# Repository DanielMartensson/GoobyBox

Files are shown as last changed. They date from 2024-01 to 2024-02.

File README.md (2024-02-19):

# GoobyBox

This project is `GoobyBox`. It's an IO-shield for Arduino UNO. 
The purpose with this project is to provide a simple solution for controlling:

 * 4 x Analog 0-10V inputs
 * 3 x PWM current 0-2A
 * 3 x Digital output current 0-2A
 * 6 x Digital input 24V protection
 * 12/24 voltage supply
 * I2C connection for LCD

This project contains two projects - Surface Mounted Technology(SMT) and Through Hole Technology Mounting (THT).

Software being used: KiCAD 6

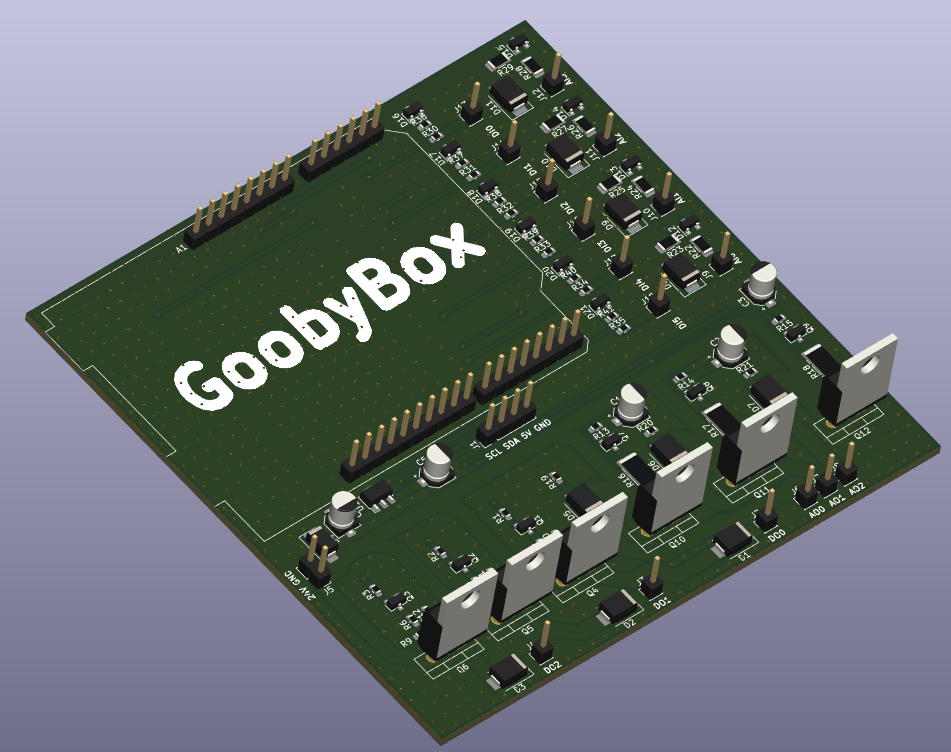
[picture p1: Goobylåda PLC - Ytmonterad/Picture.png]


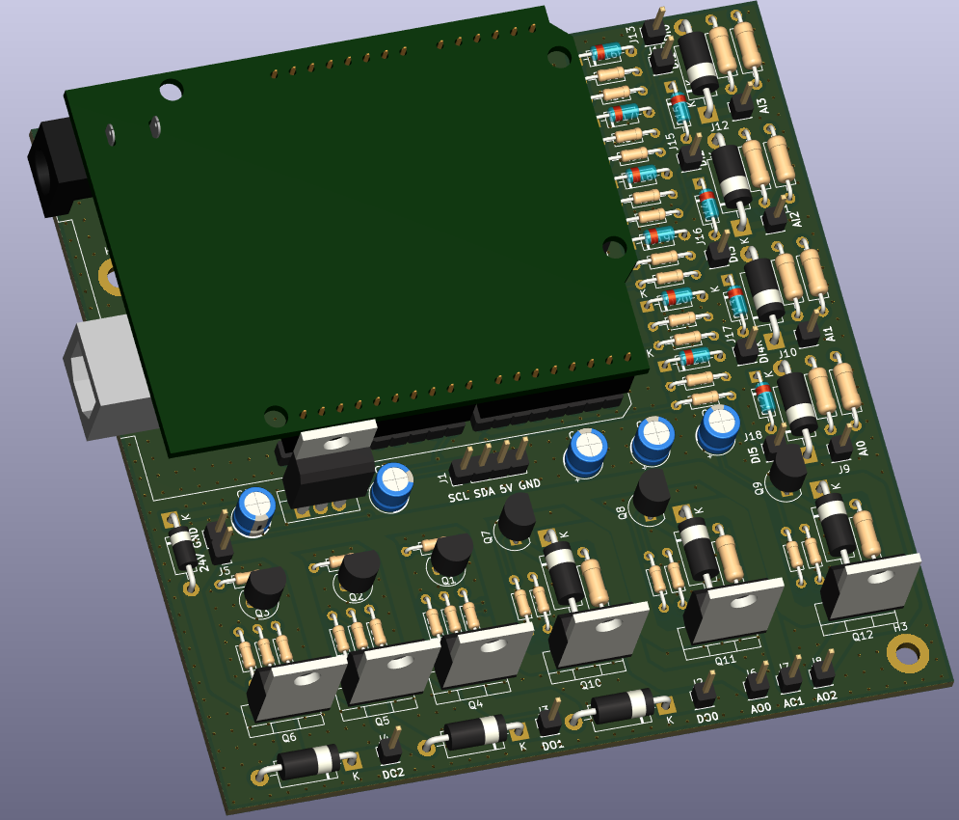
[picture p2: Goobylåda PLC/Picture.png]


This is soldered according to class 3 in the soldering and assembly standard IPC J-STD-001.

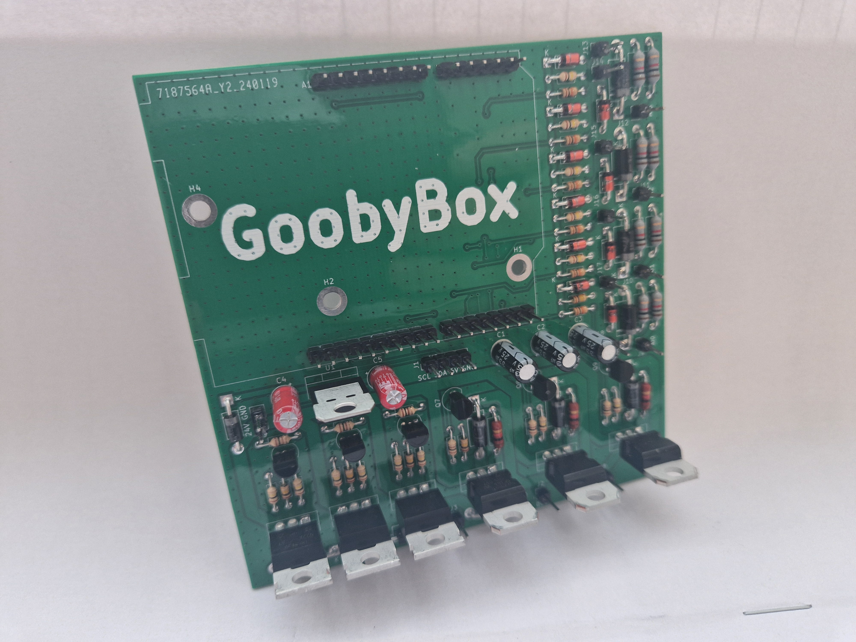
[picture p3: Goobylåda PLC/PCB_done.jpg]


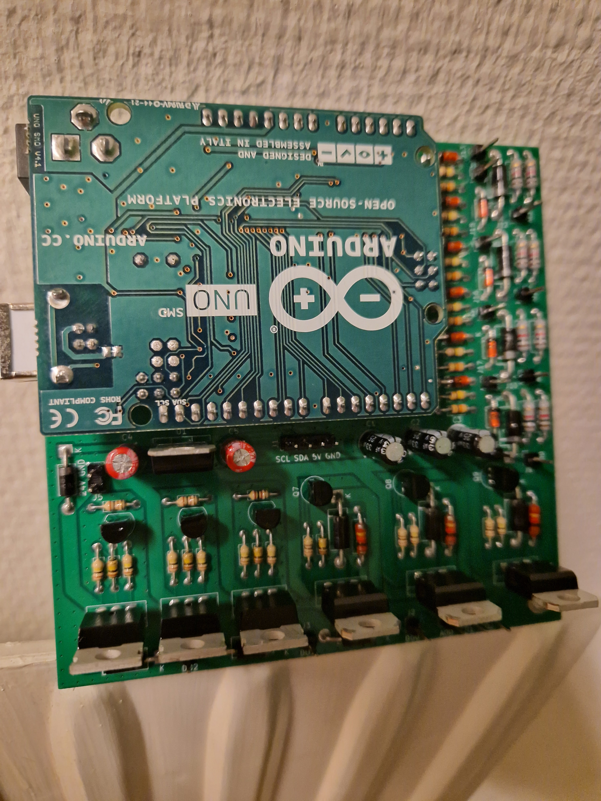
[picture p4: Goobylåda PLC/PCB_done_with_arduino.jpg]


a

Notice that I'm using a `EBC`-transistor here instead of `CBE`-transistor for the analog output.

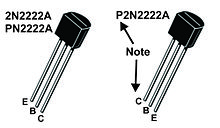
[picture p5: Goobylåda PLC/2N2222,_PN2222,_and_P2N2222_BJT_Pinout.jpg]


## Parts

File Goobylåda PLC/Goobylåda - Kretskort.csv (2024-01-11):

Source: | G:\Utbildning\Kurskatalog\4.04. Styr och Reglerteknik\7 Övningar\Laborationer\Goobylåda\Goobylåda PLC\Goobylåda - Kretskort.kicad_sch
Date: | 2022-08-26 13:30:34
Tool: | Eeschema (6.0.7)
Generator: | C:\Program Files\KiCad\6.0\bin\scripting\plugins/bom_csv_grouped_by_value.py
Component Count: | 99
Individual Components:
Item | Qty | Reference(s) | Value | LibPart | Footprint | Datasheet
 |  | A1 | Arduino_UNO_R3 | MCU_Module:Arduino_UNO_R3 | Module:Arduino_UNO_R3 | https://www.arduino.cc/en/Main/arduinoBoardUno
 |  | C1 | 33uF | Goobylåda---Kretskort-rescue:CP-Device | Capacitor_THT:CP_Radial_D5.0mm_P2.00mm
 |  | C2 | 33uF | Goobylåda---Kretskort-rescue:CP-Device | Capacitor_THT:CP_Radial_D5.0mm_P2.00mm
 |  | C3 | 33uF | Goobylåda---Kretskort-rescue:CP-Device | Capacitor_THT:CP_Radial_D5.0mm_P2.00mm
 |  | C4 | 0.33uF | Goobylåda---Kretskort-rescue:CP-Device | Capacitor_THT:CP_Radial_D5.0mm_P2.00mm
 |  | C5 | 0.1uF | Goobylåda---Kretskort-rescue:CP-Device | Capacitor_THT:CP_Radial_D5.0mm_P2.00mm
 |  | D1 | 1N5400K | Device:D | Diode_THT:D_DO-15_P10.16mm_Horizontal | ~
 |  | D2 | 1N5400K | Device:D | Diode_THT:D_DO-15_P10.16mm_Horizontal | ~
 |  | D3 | 1N5400K | Device:D | Diode_THT:D_DO-15_P10.16mm_Horizontal | ~
 |  | D4 | 600V 1A | Device:D | Diode_THT:D_DO-41_SOD81_P7.62mm_Horizontal | ~
 |  | D5 | 1N5400K | Device:D | Diode_THT:D_DO-15_P10.16mm_Horizontal | ~
 |  | D6 | 1N5400K | Device:D | Diode_THT:D_DO-15_P10.16mm_Horizontal | ~
 |  | D7 | 1N5400K | Device:D | Diode_THT:D_DO-15_P10.16mm_Horizontal | ~
 |  | D8 | 1N5400K | Device:D | Diode_THT:D_DO-15_P10.16mm_Horizontal | ~
 |  | D9 | 1N5400K | Device:D | Diode_THT:D_DO-15_P10.16mm_Horizontal | ~
 |  | D10 | 1N5400K | Device:D | Diode_THT:D_DO-15_P10.16mm_Horizontal | ~
 |  | D11 | 1N5400K | Device:D | Diode_THT:D_DO-15_P10.16mm_Horizontal | ~
 |  | D12 | 5.2V | Device:D_Zener | Diode_THT:D_DO-35_SOD27_P7.62mm_Horizontal | ~
 |  | D13 | 5.2V | Device:D_Zener | Diode_THT:D_DO-35_SOD27_P7.62mm_Horizontal | ~
 |  | D14 | 5.2V | Device:D_Zener | Diode_THT:D_DO-35_SOD27_P7.62mm_Horizontal | ~
 |  | D15 | 5.2V | Device:D_Zener | Diode_THT:D_DO-35_SOD27_P7.62mm_Horizontal | ~
 |  | D16 | 5.2V | Device:D_Zener | Diode_THT:D_DO-35_SOD27_P7.62mm_Horizontal | ~
 |  | D17 | 5.2V | Device:D_Zener | Diode_THT:D_DO-35_SOD27_P7.62mm_Horizontal | ~
 |  | D18 | 5.2V | Device:D_Zener | Diode_THT:D_DO-35_SOD27_P7.62mm_Horizontal | ~
 |  | D19 | 5.2V | Device:D_Zener | Diode_THT:D_DO-35_SOD27_P7.62mm_Horizontal | ~
 |  | D20 | 5.2V | Device:D_Zener | Diode_THT:D_DO-35_SOD27_P7.62mm_Horizontal | ~
 |  | D21 | 5.2V | Device:D_Zener | Diode_THT:D_DO-35_SOD27_P7.62mm_Horizontal | ~
 |  | J1 | LCD 1602 kontakt | Connector_Generic:Conn_01x04 | Connector_PinHeader_2.54mm:PinHeader_1x04_P2.54mm_Vertical | ~
 |  | J2 | Anslutning | Connector_Generic:Conn_01x01 | Connector_PinHeader_2.54mm:PinHeader_1x01_P2.54mm_Vertical | ~
 |  | J3 | Anslutning | Connector_Generic:Conn_01x01 | Connector_PinHeader_2.54mm:PinHeader_1x01_P2.54mm_Vertical | ~
 |  | J4 | Anslutning | Connector_Generic:Conn_01x01 | Connector_PinHeader_2.54mm:PinHeader_1x01_P2.54mm_Vertical | ~
 |  | J5 | Anslutning | Connector_Generic:Conn_01x02 | Connector_PinHeader_2.54mm:PinHeader_1x02_P2.54mm_Vertical | ~
 |  | J6 | Anslutning | Connector_Generic:Conn_01x01 | Connector_PinHeader_2.54mm:PinHeader_1x01_P2.54mm_Vertical | ~
 |  | J7 | Anslutning | Connector_Generic:Conn_01x01 | Connector_PinHeader_2.54mm:PinHeader_1x01_P2.54mm_Vertical | ~
 |  | J8 | Anslutning | Connector_Generic:Conn_01x01 | Connector_PinHeader_2.54mm:PinHeader_1x01_P2.54mm_Vertical | ~
 |  | J9 | Anslutning | Connector_Generic:Conn_01x01 | Connector_PinHeader_2.54mm:PinHeader_1x01_P2.54mm_Vertical | ~
 |  | J10 | Anslutning | Connector_Generic:Conn_01x01 | Connector_PinHeader_2.54mm:PinHeader_1x01_P2.54mm_Vertical | ~
 |  | J11 | Anslutning | Connector_Generic:Conn_01x01 | Connector_PinHeader_2.54mm:PinHeader_1x01_P2.54mm_Vertical | ~
 |  | J12 | Anslutning | Connector_Generic:Conn_01x01 | Connector_PinHeader_2.54mm:PinHeader_1x01_P2.54mm_Vertical | ~
 |  | J13 | Anslutning | Connector_Generic:Conn_01x01 | Connector_PinHeader_2.54mm:PinHeader_1x01_P2.54mm_Vertical | ~
 |  | J14 | Anslutning | Connector_Generic:Conn_01x01 | Connector_PinHeader_2.54mm:PinHeader_1x01_P2.54mm_Vertical | ~
 |  | J15 | Anslutning | Connector_Generic:Conn_01x01 | Connector_PinHeader_2.54mm:PinHeader_1x01_P2.54mm_Vertical | ~
 |  | J16 | Anslutning | Connector_Generic:Conn_01x01 | Connector_PinHeader_2.54mm:PinHeader_1x01_P2.54mm_Vertical | ~
 |  | J17 | Anslutning | Connector_Generic:Conn_01x01 | Connector_PinHeader_2.54mm:PinHeader_1x01_P2.54mm_Vertical | ~
 |  | J18 | Anslutning | Connector_Generic:Conn_01x01 | Connector_PinHeader_2.54mm:PinHeader_1x01_P2.54mm_Vertical | ~
 |  | Q1 | 2N2222 | Transistor_BJT:2N2219 | Package_TO_SOT_THT:TO-92 | http://www.onsemi.com/pub_link/Collateral/2N2219-D.PDF
 |  | Q2 | 2N2222 | Transistor_BJT:2N2219 | Package_TO_SOT_THT:TO-92 | http://www.onsemi.com/pub_link/Collateral/2N2219-D.PDF
 |  | Q3 | 2N2222 | Transistor_BJT:2N2219 | Package_TO_SOT_THT:TO-92 | http://www.onsemi.com/pub_link/Collateral/2N2219-D.PDF
 |  | Q4 | IRF9630 | Transistor_FET:IRF9383M | Package_TO_SOT_THT:TO-220-3_Vertical | https://www.infineon.com/dgdl/irf9383mpbf.pdf?fileId=5546d462533600a40153561169a11dab
 |  | Q5 | IRF9630 | Transistor_FET:IRF9383M | Package_TO_SOT_THT:TO-220-3_Vertical | https://www.infineon.com/dgdl/irf9383mpbf.pdf?fileId=5546d462533600a40153561169a11dab
 |  | Q6 | IRF9630 | Transistor_FET:IRF9383M | Package_TO_SOT_THT:TO-220-3_Vertical | https://www.infineon.com/dgdl/irf9383mpbf.pdf?fileId=5546d462533600a40153561169a11dab
 |  | Q7 | 2N2222 | Transistor_BJT:2N2219 | Package_TO_SOT_THT:TO-92 | http://www.onsemi.com/pub_link/Collateral/2N2219-D.PDF
 |  | Q8 | 2N2222 | Transistor_BJT:2N2219 | Package_TO_SOT_THT:TO-92 | http://www.onsemi.com/pub_link/Collateral/2N2219-D.PDF
 |  | Q9 | 2N2222 | Transistor_BJT:2N2219 | Package_TO_SOT_THT:TO-92 | http://www.onsemi.com/pub_link/Collateral/2N2219-D.PDF
 |  | Q10 | MJE2955T | Transistor_BJT:MJ2955 | Package_TO_SOT_THT:TO-220-3_Vertical | http://www.onsemi.com/pub_link/Collateral/2N3055-D.PDF
 |  | Q11 | MJE2955T | Transistor_BJT:MJ2955 | Package_TO_SOT_THT:TO-220-3_Vertical | http://www.onsemi.com/pub_link/Collateral/2N3055-D.PDF
 |  | Q12 | MJE2955T | Transistor_BJT:MJ2955 | Package_TO_SOT_THT:TO-220-3_Vertical | http://www.onsemi.com/pub_link/Collateral/2N3055-D.PDF
 |  | R1 | 100 | Device:R | Resistor_THT:R_Axial_DIN0204_L3.6mm_D1.6mm_P5.08mm_Horizontal | ~
 |  | R2 | 100 | Device:R | Resistor_THT:R_Axial_DIN0204_L3.6mm_D1.6mm_P5.08mm_Horizontal | ~
 |  | R3 | 100 | Device:R | Resistor_THT:R_Axial_DIN0204_L3.6mm_D1.6mm_P5.08mm_Horizontal | ~
 |  | R4 | 100k | Device:R | Resistor_THT:R_Axial_DIN0204_L3.6mm_D1.6mm_P5.08mm_Horizontal | ~
 |  | R5 | 100k | Device:R | Resistor_THT:R_Axial_DIN0204_L3.6mm_D1.6mm_P5.08mm_Horizontal | ~
 |  | R6 | 100k | Device:R | Resistor_THT:R_Axial_DIN0204_L3.6mm_D1.6mm_P5.08mm_Horizontal | ~
 |  | R7 | 100k | Device:R | Resistor_THT:R_Axial_DIN0204_L3.6mm_D1.6mm_P5.08mm_Horizontal | ~
 |  | R8 | 100k | Device:R | Resistor_THT:R_Axial_DIN0204_L3.6mm_D1.6mm_P5.08mm_Horizontal | ~
 |  | R9 | 100k | Device:R | Resistor_THT:R_Axial_DIN0204_L3.6mm_D1.6mm_P5.08mm_Horizontal | ~
 |  | R10 | 100k | Device:R | Resistor_THT:R_Axial_DIN0204_L3.6mm_D1.6mm_P5.08mm_Horizontal | ~
 |  | R11 | 100k | Device:R | Resistor_THT:R_Axial_DIN0204_L3.6mm_D1.6mm_P5.08mm_Horizontal | ~
 |  | R12 | 100k | Device:R | Resistor_THT:R_Axial_DIN0204_L3.6mm_D1.6mm_P5.08mm_Horizontal | ~
 |  | R13 | 100 | Device:R | Resistor_THT:R_Axial_DIN0204_L3.6mm_D1.6mm_P5.08mm_Horizontal | ~
 |  | R14 | 100 | Device:R | Resistor_THT:R_Axial_DIN0204_L3.6mm_D1.6mm_P5.08mm_Horizontal | ~
 |  | R15 | 100 | Device:R | Resistor_THT:R_Axial_DIN0204_L3.6mm_D1.6mm_P5.08mm_Horizontal | ~
 |  | R16 | 1k, 1W | Device:R | Resistor_THT:R_Axial_DIN0207_L6.3mm_D2.5mm_P10.16mm_Horizontal | ~
 |  | R17 | 1k, 1W | Device:R | Resistor_THT:R_Axial_DIN0207_L6.3mm_D2.5mm_P10.16mm_Horizontal | ~
 |  | R18 | 1k, 1W | Device:R | Resistor_THT:R_Axial_DIN0207_L6.3mm_D2.5mm_P10.16mm_Horizontal | ~
 |  | R19 | 100k | Device:R | Resistor_THT:R_Axial_DIN0204_L3.6mm_D1.6mm_P5.08mm_Horizontal | ~
 |  | R20 | 100k | Device:R | Resistor_THT:R_Axial_DIN0204_L3.6mm_D1.6mm_P5.08mm_Horizontal | ~
 |  | R21 | 100k | Device:R | Resistor_THT:R_Axial_DIN0204_L3.6mm_D1.6mm_P5.08mm_Horizontal | ~
 |  | R22 | 1k, 250 mW | Device:R | Resistor_THT:R_Axial_DIN0204_L3.6mm_D1.6mm_P5.08mm_Horizontal | ~
 |  | R23 | 1k, 250 mW | Device:R | Resistor_THT:R_Axial_DIN0204_L3.6mm_D1.6mm_P5.08mm_Horizontal | ~
 |  | R24 | 1k, 250 mW | Device:R | Resistor_THT:R_Axial_DIN0204_L3.6mm_D1.6mm_P5.08mm_Horizontal | ~
 |  | R25 | 1k, 250 mW | Device:R | Resistor_THT:R_Axial_DIN0204_L3.6mm_D1.6mm_P5.08mm_Horizontal | ~
 |  | R26 | 1k, 250 mW | Device:R | Resistor_THT:R_Axial_DIN0204_L3.6mm_D1.6mm_P5.08mm_Horizontal | ~
 |  | R27 | 1k, 250 mW | Device:R | Resistor_THT:R_Axial_DIN0204_L3.6mm_D1.6mm_P5.08mm_Horizontal | ~
 |  | R28 | 1k, 250 mW | Device:R | Resistor_THT:R_Axial_DIN0204_L3.6mm_D1.6mm_P5.08mm_Horizontal | ~
 |  | R29 | 1k, 250 mW | Device:R | Resistor_THT:R_Axial_DIN0204_L3.6mm_D1.6mm_P5.08mm_Horizontal | ~
 |  | R30 | 10k | Device:R | Resistor_THT:R_Axial_DIN0204_L3.6mm_D1.6mm_P5.08mm_Horizontal | ~
 |  | R31 | 10k | Device:R | Resistor_THT:R_Axial_DIN0204_L3.6mm_D1.6mm_P5.08mm_Horizontal | ~
 |  | R32 | 10k | Device:R | Resistor_THT:R_Axial_DIN0204_L3.6mm_D1.6mm_P5.08mm_Horizontal | ~
 |  | R33 | 10k | Device:R | Resistor_THT:R_Axial_DIN0204_L3.6mm_D1.6mm_P5.08mm_Horizontal | ~
 |  | R34 | 10k | Device:R | Resistor_THT:R_Axial_DIN0204_L3.6mm_D1.6mm_P5.08mm_Horizontal | ~
 |  | R35 | 10k | Device:R | Resistor_THT:R_Axial_DIN0204_L3.6mm_D1.6mm_P5.08mm_Horizontal | ~
 |  | R36 | 100k | Device:R | Resistor_THT:R_Axial_DIN0204_L3.6mm_D1.6mm_P5.08mm_Horizontal | ~
 |  | R37 | 100k | Device:R | Resistor_THT:R_Axial_DIN0204_L3.6mm_D1.6mm_P5.08mm_Horizontal | ~
 |  | R38 | 100k | Device:R | Resistor_THT:R_Axial_DIN0204_L3.6mm_D1.6mm_P5.08mm_Horizontal | ~
 |  | R39 | 100k | Device:R | Resistor_THT:R_Axial_DIN0204_L3.6mm_D1.6mm_P5.08mm_Horizontal | ~
 |  | R40 | 100k | Device:R | Resistor_THT:R_Axial_DIN0204_L3.6mm_D1.6mm_P5.08mm_Horizontal | ~
 |  | R41 | 100k | Device:R | Resistor_THT:R_Axial_DIN0204_L3.6mm_D1.6mm_P5.08mm_Horizontal | ~
 |  | U1 | LM7812_TO220 | Regulator_Linear:LM7812_TO220 | Package_TO_SOT_THT:TO-220-3_Vertical | https://www.onsemi.cn/PowerSolutions/document/MC7800-D.PDF
Collated Components:
Item | Qty | Reference(s) | Value | LibPart | Footprint | Datasheet
1 | 1 | A1 | Arduino_UNO_R3 | MCU_Module:Arduino_UNO_R3 | Module:Arduino_UNO_R3 | https://www.arduino.cc/en/Main/arduinoBoardUno
2 | 3 | C1, C2, C3 | 33uF | Goobylåda---Kretskort-rescue:CP-Device | Capacitor_THT:CP_Radial_D5.0mm_P2.00mm
3 | 1 | C4 | 0.33uF | Goobylåda---Kretskort-rescue:CP-Device | Capacitor_THT:CP_Radial_D5.0mm_P2.00mm
4 | 1 | C5 | 0.1uF | Goobylåda---Kretskort-rescue:CP-Device | Capacitor_THT:CP_Radial_D5.0mm_P2.00mm
5 | 10 | D1, D2, D3, D5, D6, D7, D8, D9, D10, D11 | 1N5400K | Device:D | Diode_THT:D_DO-15_P10.16mm_Horizontal | ~
6 | 1 | D4 | 600V 1A | Device:D | Diode_THT:D_DO-41_SOD81_P7.62mm_Horizontal | ~
7 | 10 | D12, D13, D14, D15, D16, D17, D18, D19, D20, D21 | 5.2V | Device:D_Zener | Diode_THT:D_DO-35_SOD27_P7.62mm_Horizontal | ~
8 | 1 | J1 | LCD 1602 kontakt | Connector_Generic:Conn_01x04 | Connector_PinHeader_2.54mm:PinHeader_1x04_P2.54mm_Vertical | ~
9 | 16 | J2, J3, J4, J6, J7, J8, J9, J10, J11, J12, J13, J14, J15, J16, J17, J18 | Anslutning | Connector_Generic:Conn_01x01 | Connector_PinHeader_2.54mm:PinHeader_1x01_P2.54mm_Vertical | ~
10 | 1 | J5 | Anslutning | Connector_Generic:Conn_01x02 | Connector_PinHeader_2.54mm:PinHeader_1x02_P2.54mm_Vertical | ~
11 | 6 | Q1, Q2, Q3, Q7, Q8, Q9 | 2N2222 | Transistor_BJT:2N2219 | Package_TO_SOT_THT:TO-92 | http://www.onsemi.com/pub_link/Collateral/2N2219-D.PDF
12 | 3 | Q4, Q5, Q6 | IRF9630 | Transistor_FET:IRF9383M | Package_TO_SOT_THT:TO-220-3_Vertical | https://www.infineon.com/dgdl/irf9383mpbf.pdf?fileId=5546d462533600a40153561169a11dab
13 | 3 | Q10, Q11, Q12 | MJE2955T | Transistor_BJT:MJ2955 | Package_TO_SOT_THT:TO-220-3_Vertical | http://www.onsemi.com/pub_link/Collateral/2N3055-D.PDF
14 | 6 | R1, R2, R3, R13, R14, R15 | 100 | Device:R | Resistor_THT:R_Axial_DIN0204_L3.6mm_D1.6mm_P5.08mm_Horizontal | ~
15 | 18 | R4, R5, R6, R7, R8, R9, R10, R11, R12, R19, R20, R21, R36, R37, R38, R39, R40, R41 | 100k | Device:R | Resistor_THT:R_Axial_DIN0204_L3.6mm_D1.6mm_P5.08mm_Horizontal | ~
16 | 3 | R16, R17, R18 | 1k, 1W | Device:R | Resistor_THT:R_Axial_DIN0207_L6.3mm_D2.5mm_P10.16mm_Horizontal | ~
17 | 8 | R22, R23, R24, R25, R26, R27, R28, R29 | 1k, 250 mW | Device:R | Resistor_THT:R_Axial_DIN0204_L3.6mm_D1.6mm_P5.08mm_Horizontal | ~
18 | 6 | R30, R31, R32, R33, R34, R35 | 10k | Device:R | Resistor_THT:R_Axial_DIN0204_L3.6mm_D1.6mm_P5.08mm_Horizontal | ~
19 | 1 | U1 | LM7812_TO220 | Regulator_Linear:LM7812_TO220 | Package_TO_SOT_THT:TO-220-3_Vertical | https://www.onsemi.cn/PowerSolutions/document/MC7800-D.PDF

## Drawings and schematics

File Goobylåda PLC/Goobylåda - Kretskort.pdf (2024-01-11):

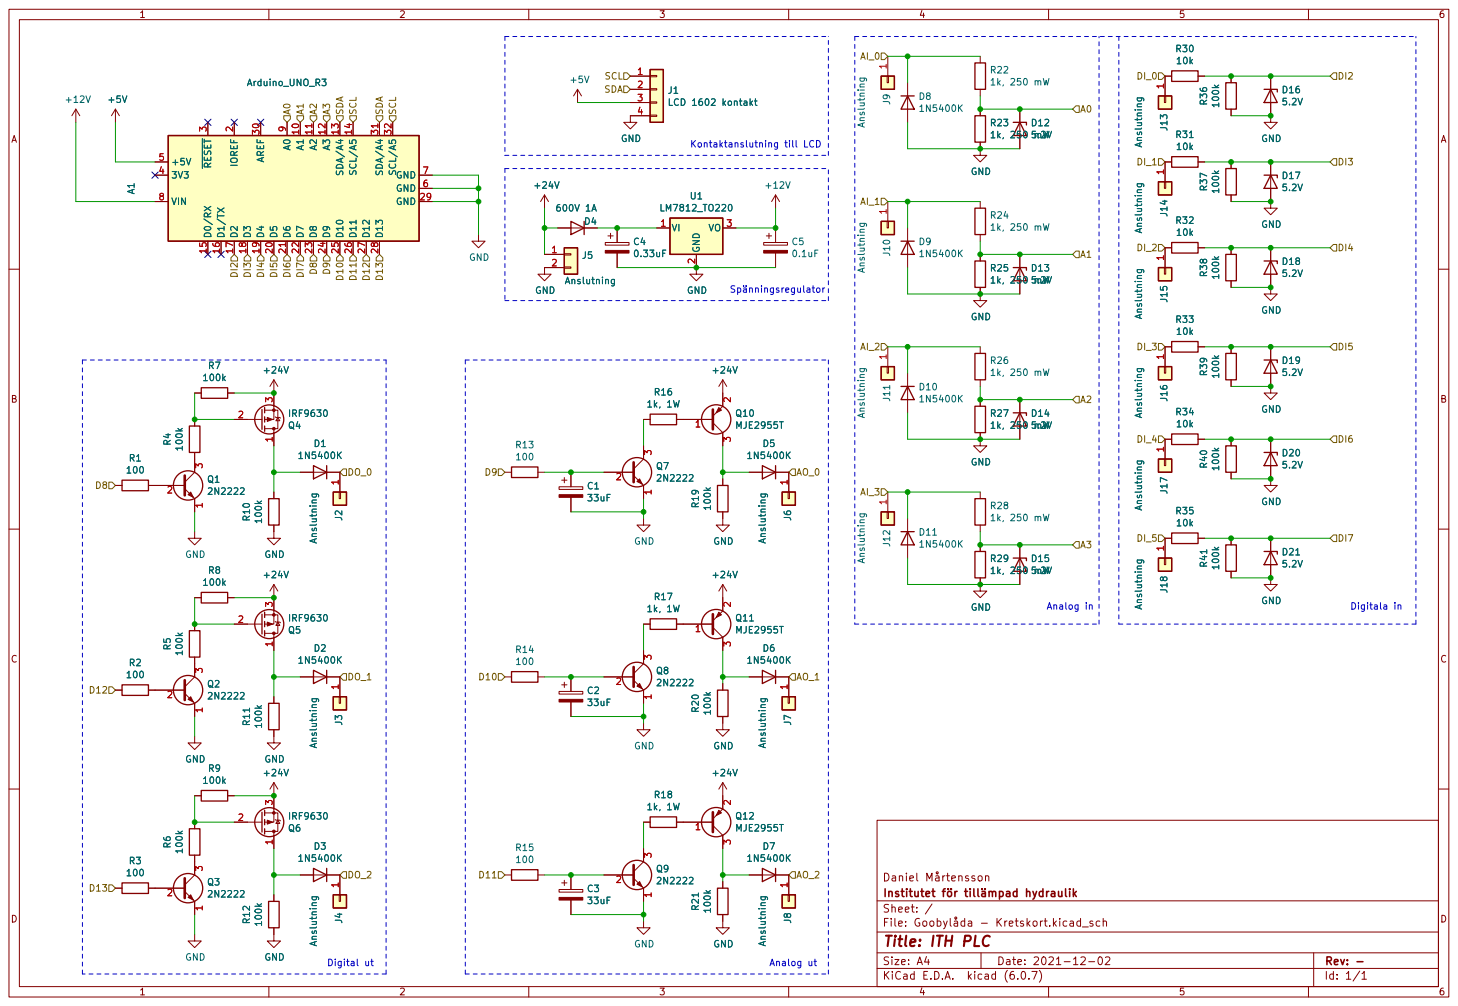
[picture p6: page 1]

2 3 +24V GND R19 100k A1 Arduino_UNO_R3 A1 10 A2 11 A3 12 SDA/A4 13 SCL/A5 14 D0/RX 15 D1/TX 16 D2 17 D3 18 D4 19 IOREF

2 D5 20 D6 21 D7 22 D8 23 D9 24 D10 25 D11 26 D12 27 D13 28 GND 29 ~{RESET} 3 AREF 30 SDA/A4 31 SCL/A5 32

Id: 1/1 Title: ITH PLC

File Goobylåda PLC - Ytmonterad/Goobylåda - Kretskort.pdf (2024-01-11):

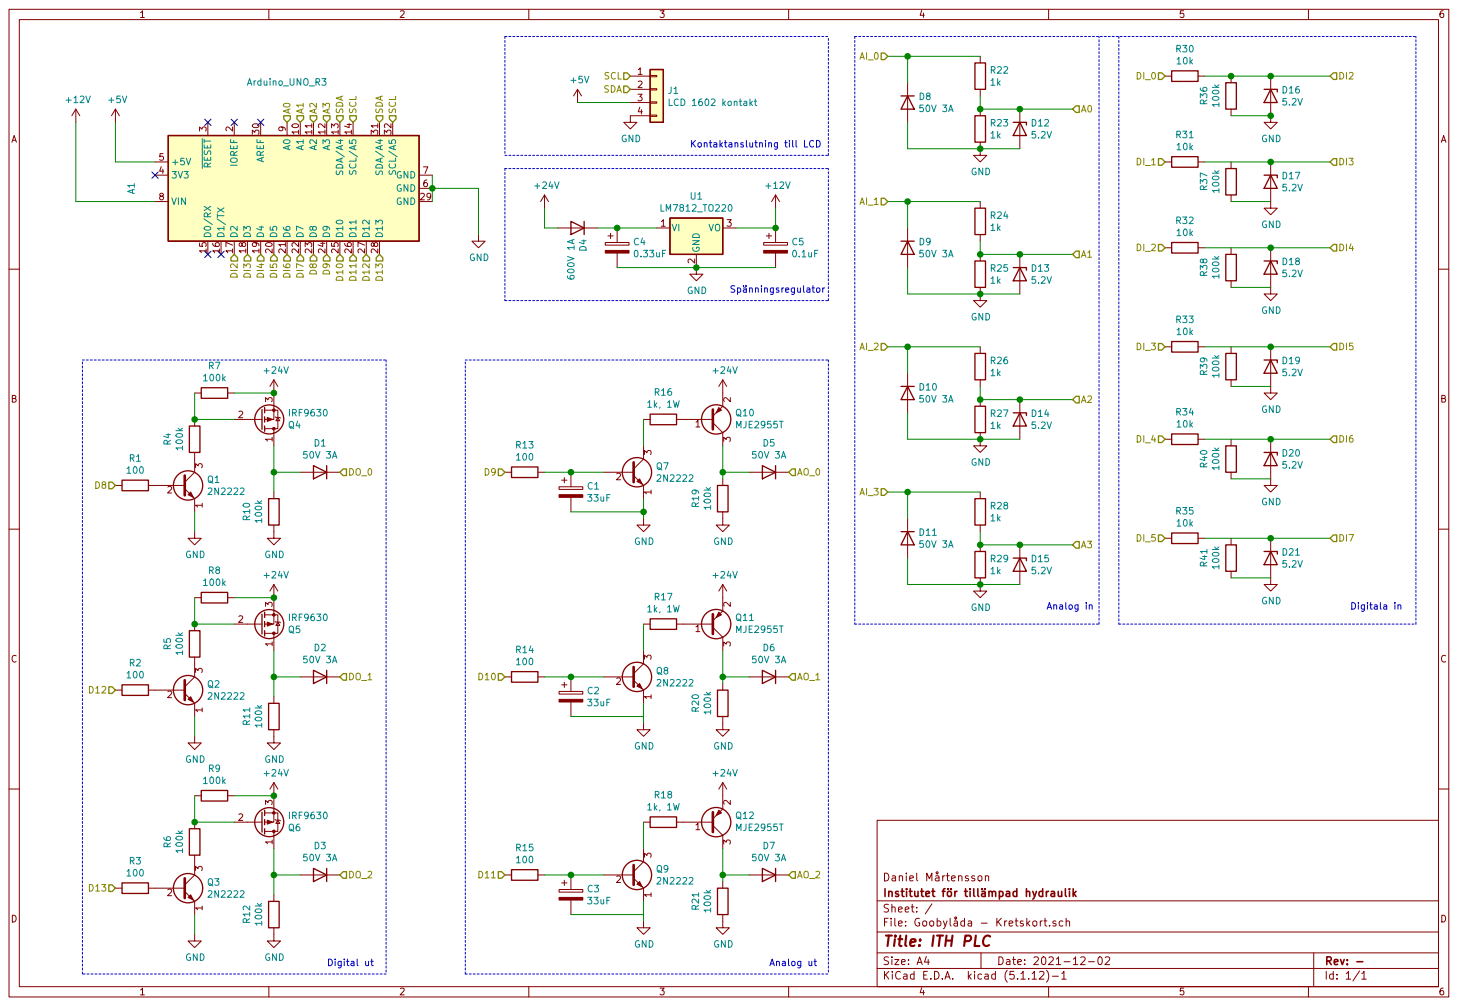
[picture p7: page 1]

Daniel Mårtensson
Institutet för tillämpad hydraulik
File: Goobylåda - Kretskort.sch Sheet: /
Id: 1/1 Title: ITH PLC

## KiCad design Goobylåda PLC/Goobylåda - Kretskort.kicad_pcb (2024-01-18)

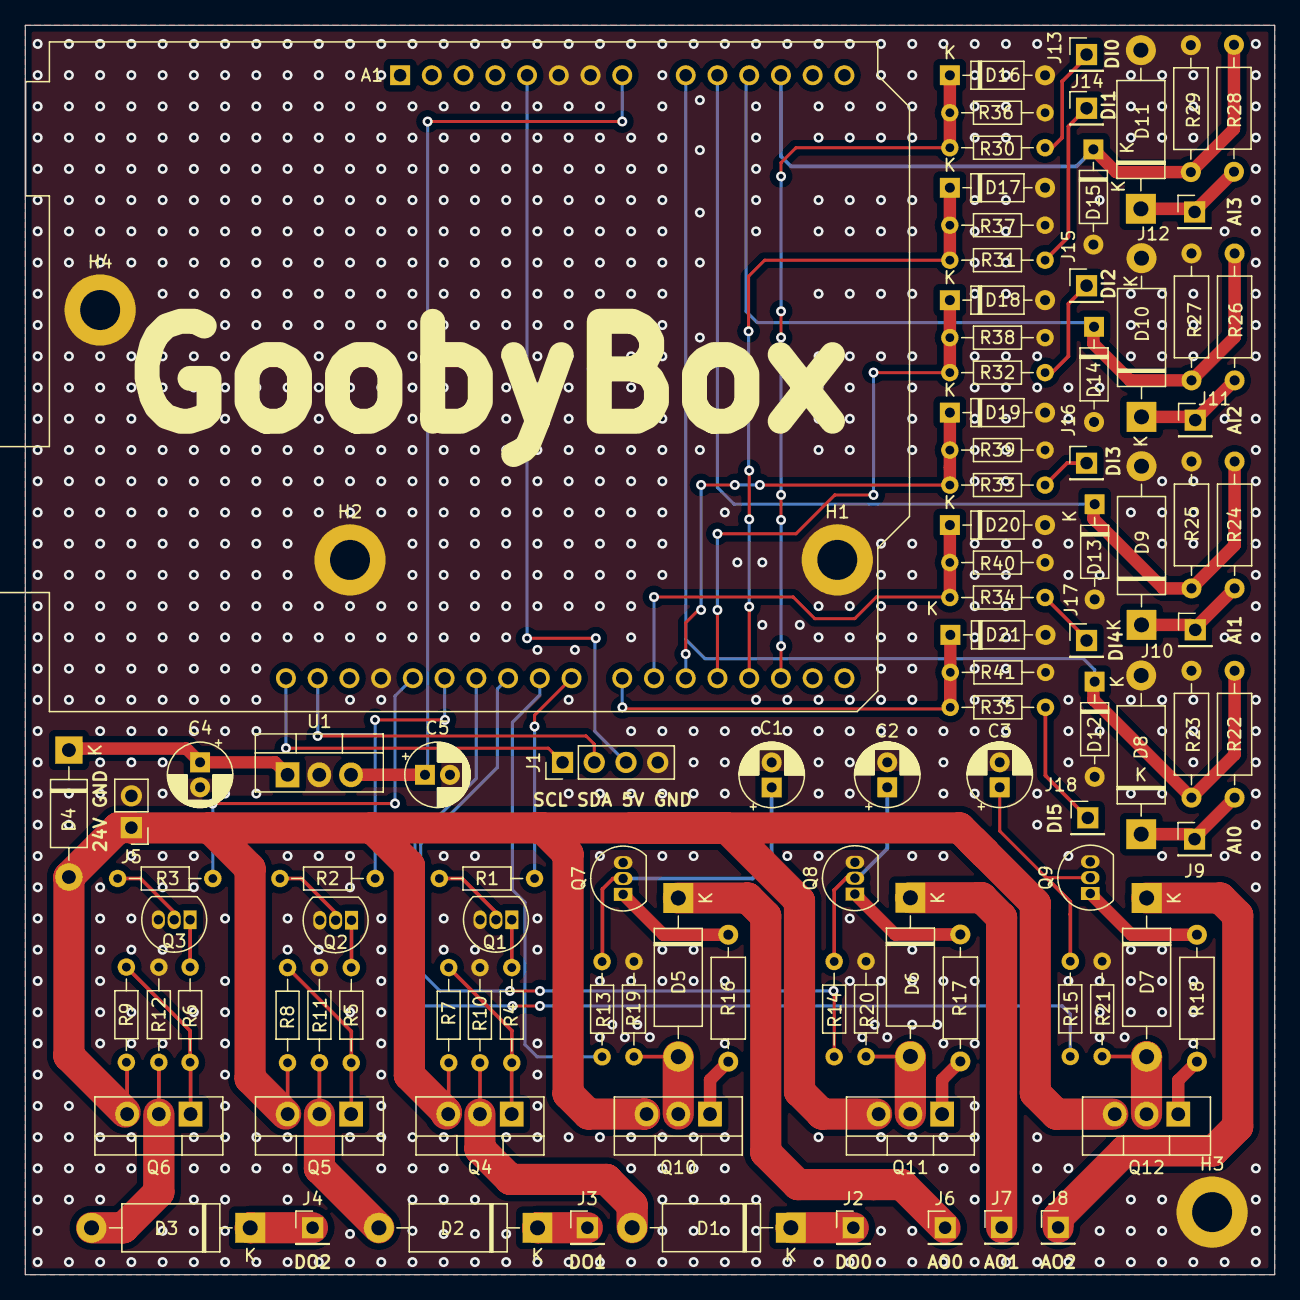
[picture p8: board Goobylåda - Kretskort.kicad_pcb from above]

Board: 2 copper layers, 100.0 x 100.0 mm, 103 parts (0 on the bottom side), 63 nets.

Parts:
A1: Arduino_UNO_R3
C1, C2, C3: 33uF; CP_Radial_D5.0mm_P2.00mm
C4: 0.33uF; CP_Radial_D5.0mm_P2.00mm
C5: 0.1uF; CP_Radial_D5.0mm_P2.00mm
D1, D2, D3, D5, D6, D7, D8, D9, D10, D11: 1N5400K; D_DO-15_P12.70mm_Horizontal
D4: 600V 1A; D_DO-41_SOD81_P10.16mm_Horizontal
D12, D13, D14, D15, D16, D17, D18, D19, D20, D21: 5.2V; D_DO-35_SOD27_P7.62mm_Horizontal
H1, H2, H3, H4: M3; MountingHole_3.2mm_M3_ISO7380_Pad
J1: LCD 1602 kontakt; PinHeader_1x04_P2.54mm_Vertical
J2, J3, J4, J6, J7, J8, J9, J10, J11, J12, J13, J14, J15, J16, J17, J18: Anslutning; PinHeader_1x01_P2.54mm_Vertical
J5: Anslutning; PinHeader_1x02_P2.54mm_Vertical
Q1, Q2, Q3, Q7, Q8, Q9: 2N2222; TO-92_Inline
Q4, Q5, Q6: IRF9630; TO-220-3_Vertical
Q10, Q11, Q12: MJE29555T; TO-220-3_Vertical
R1, R2, R3, R13, R14, R15: 100; R_Axial_DIN0204_L3.6mm_D1.6mm_P7.62mm_Horizontal
R4, R5, R6, R7, R8, R9, R10, R11, R12, R19, R20, R21, R36, R37, R38, R39, R40, R41: 100k; R_Axial_DIN0204_L3.6mm_D1.6mm_P7.62mm_Horizontal
R16, R17, R18: 1k, 1W; R_Axial_DIN0207_L6.3mm_D2.5mm_P10.16mm_Horizontal
R22, R23, R24, R25, R26, R27, R28, R29: 1k, 250 mW; R_Axial_DIN0207_L6.3mm_D2.5mm_P10.16mm_Horizontal
R30, R31, R32, R33, R34, R35: 10k; R_Axial_DIN0204_L3.6mm_D1.6mm_P7.62mm_Horizontal
U1: LM7812_TO220; TO-220-3_Vertical

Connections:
+5V: A1.5 (+5V), J1.3
+12V: A1.8 (VIN), C5.1, U1.3 (VO)
+24V: D4.2 (A), J5.1, Q4.3 (S), Q5.3 (S), Q6.3 (S), Q10.3 (E), Q11.3 (E), Q12.3 (E), R7.1, R8.1, R9.1
/A0: A1.9 (A0), D12.1 (K), R22.2, R23.1
/A1: A1.10 (A1), D13.1 (K), R24.2, R25.1
/A2: A1.11 (A2), D14.1 (K), R26.2, R27.1
/A3: A1.12 (A3), D15.1 (K), R28.2, R29.1
/AI_0: D8.1 (K), J9.1, R22.1
/AI_1: D9.1 (K), J10.1, R24.1
/AI_2: D10.1 (K), J11.1, R26.1
/AI_3: D11.1 (K), J12.1, R28.1
/AO_0: D5.1 (K), J6.1
/AO_1: D6.1 (K), J7.1
/AO_2: D7.1 (K), J8.1
/D8: A1.23 (D8), R1.2
/D9: A1.24 (D9), R13.2
/D10: A1.25 (D10), R14.2
/D11: A1.26 (D11), R15.2
/D12: A1.27 (D12), R2.2
/D13: A1.28 (D13), R3.2
/DI2: A1.17 (D2), D16.1 (K), R30.1, R36.1
/DI3: A1.18 (D3), D17.1 (K), R31.1, R37.1
/DI4: A1.19 (D4), D18.1 (K), R32.1, R38.1
/DI5: A1.20 (D5), D19.1 (K), R33.1, R39.1
/DI6: A1.21 (D6), D20.1 (K), R34.1, R40.1
/DI7: A1.22 (D7), D21.1 (K), R35.1, R41.1
/DI_0: J13.1, R30.2
/DI_1: J14.1, R31.2
/DI_2: J15.1, R32.2
/DI_3: J16.1, R33.2
/DI_4: J17.1, R34.2
/DI_5: J18.1, R35.2
/DO_0: D1.1 (K), J2.1
/DO_1: D2.1 (K), J3.1
/DO_2: D3.1 (K), J4.1
/SCL: A1.32 (SCL/A5), J1.1
/SDA: A1.31 (SDA/A4), J1.2
GND: A1.6 (GND), A1.7 (GND), A1.29 (GND), C1.2, C2.2, C3.2, C4.2, C5.2, D8.2 (A), D9.2 (A), D10.2 (A), D11.2 (A), D12.2 (A), D13.2 (A), D14.2 (A), D15.2 (A), D16.2 (A), D17.2 (A), D18.2 (A), D19.2 (A), D20.2 (A), D21.2 (A), H1.1, H2.1, H3.1, H4.1, J1.4, J5.2, Q1.3 (E), Q2.3 (E), Q3.3 (E), Q7.3 (E), Q8.3 (E), Q9.3 (E), R10.2, R11.2, R12.2, R19.2, R20.2, R21.2, R23.2, R25.2, R27.2, R29.2, R36.2, R37.2, R38.2, R39.2, R40.2, R41.2, U1.2 (GND)
unnamed: C1.1, Q7.2 (B), R13.1
unnamed: C2.1, Q8.2 (B), R14.1
unnamed: C3.1, Q9.2 (B), R15.1
unnamed: C4.1, D4.1 (K), U1.1 (VI)
unnamed: D1.2 (A), Q4.2 (D), R10.1
unnamed: D2.2 (A), Q5.2 (D), R11.1
unnamed: D3.2 (A), Q6.2 (D), R12.1
unnamed: D5.2 (A), Q10.2 (C), R19.1
unnamed: D6.2 (A), Q11.2 (C), R20.1
unnamed: D7.2 (A), Q12.2 (C), R21.1
unnamed: Q1.1 (C), R4.2
unnamed: Q1.2 (B), R1.1
unnamed: Q2.1 (C), R5.2
unnamed: Q2.2 (B), R2.1
unnamed: Q3.1 (C), R6.2
unnamed: Q3.2 (B), R3.1
unnamed: Q4.1 (G), R4.1, R7.2
unnamed: Q5.1 (G), R5.1, R8.2
unnamed: Q6.1 (G), R6.1, R9.2
unnamed: Q7.1 (C), R16.2
unnamed: Q8.1 (C), R17.2
unnamed: Q9.1 (C), R18.2
unnamed: Q10.1 (B), R16.1
unnamed: Q11.1 (B), R17.1
unnamed: Q12.1 (B), R18.1

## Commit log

2024-01-11 First upload
    [Goobylåda - Kretskort - BACKUP.kicad_pcb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]
2024-01-14 Update for THT
    [Goobylåda - Kretskort.kicad_pcb, Goobylåda - Kretskort.kicad_sch]
2024-01-17 new picture for GoobyBox
    [Goobylåda - Kretskort-B_Cu.gbl, Goobylåda - Kretskort-B_Mask.gbs, Goobylåda - Kretskort-B_Paste.gbp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]
2024-01-18 mounting holes
    [Goobylåda - Kretskort-B_Cu.gbl, Goobylåda - Kretskort-B_Mask.gbs, Goobylåda - Kretskort-B_Paste.gbp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]
2024-01-19 update schematic
2024-02-15 Update PCB board
2024-02-19 add with Arduino
